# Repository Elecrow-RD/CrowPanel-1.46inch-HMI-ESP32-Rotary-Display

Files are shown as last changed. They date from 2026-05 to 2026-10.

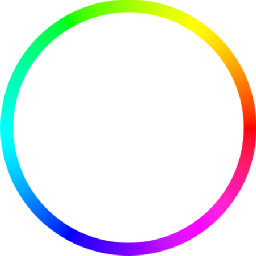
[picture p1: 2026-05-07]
factory_soucecode/1_46_SquareLine_Studio_Project/cache/thumb_327526221power_on_light_400@3x(1).png

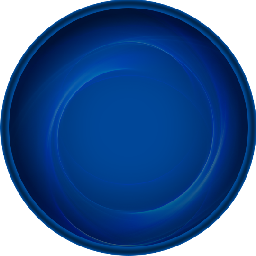
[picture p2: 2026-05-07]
factory_soucecode/1_46_SquareLine_Studio_Project/cache/thumb_1871530951device_control_bj_01@3x.png

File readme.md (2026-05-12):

### 1, Product picture



### 2, Product version number

| | Hardware | Software | Remark |
| ---- | --- | --- | --- |
| 1 | V1.0 | V1.0 | latest |

### 3, product information

#### Display Module Specifications
| Main Chip: ESP32-S3R8  | |
| --- | --- |
| Processor | Equipped with high-performance Xtensa 32-bit LX7 dual-core processor, with a main frequency of up to 240MHz |
| System memory | 512KB SRAM、8M PSRAM |
| Storage | 16M Flash |
| Screen | |
| Size | 1.46 inch |
| Screen Type | IPS |
| Touch Type | Capacitive Touch |
| Resolution | 360*360 |
| Wireless Communication | |
| Bluetooth | Bluetooth Low Energy and Bluetooth 5.0 |
| WiFi | Support 802.11a/b/g/n，2.4GH |
| Hardware | |
| UART Interface | 2x UART, ZX-MX 1.25-4P |
| I2C interface | ZX-MX 1.25-4P |
| FPC connector | 12P, Power supply burning port, Pitch: 0.5 mm. |
| Button | RESET button, BOOT button, confirmation button (knob press switch) |
| LED Light | Power indicator, LED ambient light |
| Other | |
| Power Input | 5V/1A |
| Operating temperature  | -20~65℃ |
| Storage temperature | -40~80℃ |
| Operation Power | Module：DC5V  Main Chip：3.3V |
| Size | 60\*60*27.5mm |
| Shell | Plastic + acrylic |
| Net Weight | 60g |

### 4, Use the driver module

| Name | dependency library |
| ---- | --- |
| LVGL | lvgl/lvgl@8.3.11 |

### 5,Quick Start

##### Arduino IDE starts

1.Download the library files used by this product to the 'libraries' folder.

C:\Users\Documents\Arduino\libraries\



2.Open the Arduino IDE



3.Open the code configuration environment and burn it.



### 6,Folder structure.

|--3D file： Contains 3D model files (.stp) for the hardware. These files can be used for visualization, enclosure design, or integration into CAD software.

|--Datasheet: Includes datasheets for components used in the project, providing detailed specifications, electrical characteristics, and pin configurations.

|--Eagle_SCH&PCB: Contains **Eagle CAD** schematic (`.sch`) and PCB layout (`.brd`) files. These are used for circuit design and PCB manufacturing.

|--example: Provides example code and projects to demonstrate how to use the hardware and libraries. These examples help users get started quickly.

|--factory_firmware: Stores pre-compiled factory firmware that can be directly flashed onto the device. This ensures the device runs the default functionality.

|--factory_sourcecode: Contains the source code for the factory firmware, allowing users to modify and rebuild the firmware as needed.

### 7,Pin definition

| Function | GPIO |
| --- | --- |
| LCD SCLK | GPIO10 |
| LCD MOSI | GPIO11 |
| LCD CS | GPIO9  |
| LCD DC | GPIO3  |
| LCD RST | GPIO14 |
| Touch SDA | GPIO6  |
| Touch SCL | GPIO7  |
| Touch INT | GPIO5  |
| Touch RST | GPIO13 |
| Backlight | GPIO46 |
| Encoder A | GPIO45 |
| Encoder B | GPIO42 |
| Encoder Switch | GPIO41 |
| Power LED | GPIO40 |
| RGB LED | GPIO48 |
| I2C_SDA | GPIO38 |
| I2C_SCL | GPIO39 |

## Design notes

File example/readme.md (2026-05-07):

**Arduino**: This folder contains sample programs for the Arduino platform, which is known for its ease of use and versatility in creating interactive electronic projects.

#### NOTE!!!:

#### 1.When running this program , you need to download the officially provided libraries and place them in the libraries of arduino. 

#### 2.esp32 version needs to be 2.0.14 the version of the libraries is the same as the officially provided version.

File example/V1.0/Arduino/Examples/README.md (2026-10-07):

# ESP32-S3 1.46 examples

These six sketches are hardware-adapted versions of `1.28Examples`. They target the 360x360 ST77961 display on the 1.46 board: LCD SPI 10/11/3/9/14, touch I2C SDA/SCL 6/7 with CST816T reset/interrupt 13/5, backlight GPIO46, power rails GPIO1/2, and indicator GPIO40. Encoder pins remain 45/42/button 41; DHT20 uses `Wire1` on 38/39. Each lesson that needs the shared display hardware includes its own Common_1_46.h, so every folder can be opened independently. Make the bundled `Arduino/RotaryScreen_1_46_Code_Core3_LVGL9/libraries` available as the sketchbook library directory.

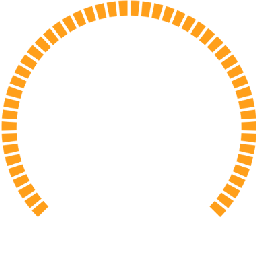
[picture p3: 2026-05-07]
factory_soucecode/1_46_SquareLine_Studio_Project/cache/thumb_1965436346bar_orange@3x.png

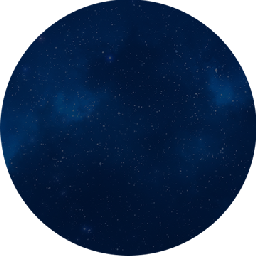
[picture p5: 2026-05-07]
factory_soucecode/1_46_SquareLine_Studio_Project/cache/thumb_440600382360_1.png

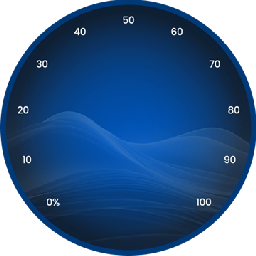
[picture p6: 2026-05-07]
factory_soucecode/1_46_SquareLine_Studio_Project/cache/thumb_309294278360_bg.png

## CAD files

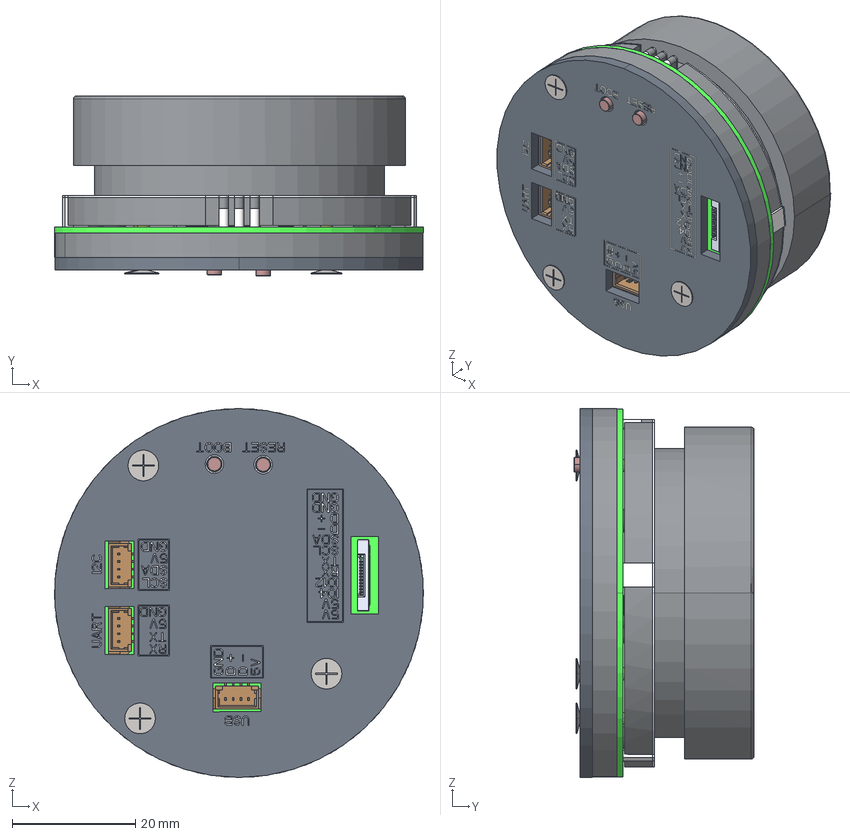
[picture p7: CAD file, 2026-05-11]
3D file/1.46_Rotary_Display_asm_1_asm.stp
60.0 x 29.3 x 60.0 mm
DIGAI-001_1
LED-SMD_WS2812B-4020_LED-SMD_WS x 8
SW-SMD_HX-4_5X4_5X5_0H-B3JTP__1 x 2
SW-SMD_HX-4_5X4_5X5_0H-B3JTP__2 x 2
FPC-SMD_12P-P0_50_X05C2012TZ__1
FPC-SMD_12P-P0_50_X05C2012TZ__2
FPC-SMD_12P-P0_50_X05C2012TZ__3
FPC-SMD_12P-P0_50_X05C2012TZ__4
FPC-SMD_12P-P0_50_X05C2012TZ__5
FPC-SMD_12P-P0_50_X05C2012TZ__6
FPC-SMD_12P-P0_50_X05C2012TZ__7
FPC-SMD_12P-P0_50_X05C2012TZ__8
FPC-SMD_12P-P0_50_X05C2012TZ__9
FPC-SMD_12P-P0_50_X05C2012TZ_10
FPC-SMD_12P-P0_50_X05C2012TZ_11
FPC-SMD_12P-P0_50_X05C2012TZ_13
FPC-SMD_12P-P0_50_X05C2012TZ_14
FPC-SMD_12P-P0_50_X05C2012TZ_12
CONN-SMD_4P-P1_25_MEGASTAR_ZX_1 x 2
CONN-SMD_4P-P1_25_MEGASTAR_ZX_2 x 2
CONN-SMD_4P-P1_25_MEGASTAR_ZX_3 x 2
P146B001-IPS_1
PRT0008_1_1
PRT0008_1_2
PRT0008_1_3
PRT0008_1_4
PRT0012_1
PRT0013_1
FPC-SMD_14P-P0_50_HC-FPC-05-2_1
FPC-SMD_14P-P0_50_HC-FPC-05-2_2
FPC-SMD_14P-P0_50_HC-FPC-05-2_3
FPC-SMD_14P-P0_50_HC-FPC-05-2_4
FPC-SMD_14P-P0_50_HC-FPC-05-2_5
FPC-SMD_14P-P0_50_HC-FPC-05-2_6
FPC-SMD_14P-P0_50_HC-FPC-05-2_7
FPC-SMD_14P-P0_50_HC-FPC-05-2_8
FPC-SMD_14P-P0_50_HC-FPC-05-2_9
FPC-SMD_14P-P0_50_HC-FPC-05-_10
FPC-SMD_14P-P0_50_HC-FPC-05-_11
FPC-SMD_14P-P0_50_HC-FPC-05-_12
FPC-SMD_14P-P0_50_HC-FPC-05-_13
FPC-SMD_14P-P0_50_HC-FPC-05-_14
FPC-SMD_14P-P0_50_HC-FPC-05-_15
FPC-SMD_14P-P0_50_HC-FPC-05-_16
FPC-SMD_14P-P0_50_HC-FPC-05-_17
FPC-SMD_14P-P0_50_HC-FPC-05-_18
FPC-SMD_14P-P0_50_HC-FPC-05-_19
FPC-SMD_14P-P0_50_HC-FPC-05-_20
FPC-SMD_14P-P0_50_HC-FPC-05-_21
FPC-SMD_14P-P0_50_HC-FPC-05-_22
FPC-SMD_14P-P0_50_HC-FPC-05-_23
FPC-SMD_14P-P0_50_HC-FPC-05-_24
FPC-SMD_14P-P0_50_HC-FPC-05-_25
FPC-SMD_14P-P0_50_HC-FPC-05-_26
FPC-SMD_14P-P0_50_HC-FPC-05-_27
FPC-SMD_14P-P0_50_HC-FPC-05-_28
FPC-SMD_14P-P0_50_HC-FPC-05-_29
FPC-SMD_14P-P0_50_HC-FPC-05-_30
FPC-SMD_14P-P0_50_HC-FPC-05-_31
ABF24D66-D606-482B-91E4-7AD95_1 x 3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

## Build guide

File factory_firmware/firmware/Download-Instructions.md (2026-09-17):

# RotaryScreen 1.46 Firmware Download Guide

> Version date: 2026-09-16
> What's new in this release: improved touch swipe feel when selecting items in the main menu (touch response on the detail page improved as well)

## Firmware Configuration

- Chip: ESP32-S3 (requires 16 MB Flash + OPI PSRAM)
- Arduino ESP32 Core: 3.3.8-cn
- Flash: 16 MB, 80 MHz, DIO
- PSRAM: OPI PSRAM
- Partition scheme: elecrow_s3 (10 MB APP)
- Boot sequence: shows the Screen0 splash image, enters the main menu (Screen1) after about 1.5 seconds

## Interaction Notes for This Version

| Action | Location | Effect |
| --- | --- | --- |
| Swipe left/right (≥30 px) | Main menu | Switch between Volume / Temp / Light, one step per swipe |
| Rotate the knob | Main menu | Same as above, switches one step at a time |
| Short press the knob | Main menu | Enter the detail page of the currently selected item |
| Drag the ring | Detail page | Adjust volume / temperature / brightness |
| Double press the knob | Detail page | Return to the main menu |

Main menu swiping uses a **one step per touch** strategy: continuing to swipe without lifting your finger will not skip through multiple steps — you need to lift your finger and swipe again to advance another step. This is an intentional design choice to avoid accidentally scrolling past several options on a mis-touch.

## Recommended Method: Flash the Complete Firmware in One Go

File to use: `RotaryScreen_1_46_ESP32S3_16MB_merged.bin` (16 MB, contains bootloader + partition table + application)

1. Connect the board with a USB cable.
2. Check Device Manager for the newly added COM port, for example `COM6`.
3. If the device does not enter download mode automatically: hold BOOT, briefly press RESET, then release BOOT.
4. Open a terminal in this directory and run:

```bat
flash_firmware.bat COM6
```

Replace `COM6` with the actual port. The device resets automatically after flashing succeeds.

You can also run esptool directly:

```bat
esptool.exe --chip esp32s3 --port COM6 --baud 921600 --before default-reset --after hard-reset write-flash -z --flash-mode dio --flash-freq 80m --flash-size 16MB 0x0 RotaryScreen_1_46_ESP32S3_16MB_merged.bin
```

If the connection is unstable, change the baud rate from `921600` to `115200`.

## Espressif Flash Download Tool

1. Select `ESP32-S3` as the chip and `Develop` as the mode.
2. Add `RotaryScreen_1_46_ESP32S3_16MB_merged.bin`.
3. Set the download address to `0x0`.
4. Set SPI SPEED to `80MHz`, SPI MODE to `DIO`, and FLASH SIZE to `16MB`.
5. Select the correct COM port and click START.

## Separate Firmware Flash Addresses

If you need to download the files separately, the files and addresses are as follows:

| Address | File |
| --- | --- |
| `0x0000` | `bootloader.bin` |
| `0x8000` | `partitions.bin` |
| `0xE000` | `boot_app0.bin` |
| `0x10000` | `RotaryScreen_1_46_app.bin` |

Note: when updating only the application, flash just `RotaryScreen_1_46_app.bin` to `0x10000`; for a first-time flash or when the partition layout changes, use the complete merged firmware.

## SHA-256 Checksums

See `SHA256SUMS.txt` in the same directory for the full list.

```text
RotaryScreen_1_46_ESP32S3_16MB_merged.bin  a19d0791915d7bf4e098c4388c402b202f067aa18c66ec787de13995972835cd
RotaryScreen_1_46_app.bin                  7330dbcaa128e9011c08a478efa70d9e7593d83b7891748ba2d3a0be162009bc
bootloader.bin                             b68c1ed33c43a4290375213f24d608c125e31e22880d16d4a5dcba89e083716d
partitions.bin                             0b9c3ff6810d66db6f419056f0fe49b118d8cf251049677e9475fae3fd0fb5d3
boot_app0.bin                              f94c5d786a7a8fab06ac5d10e33bf37711a6697636dc037559ea19cc410a17f0
```

Verification command on Windows:

```bat
certutil -hashfile RotaryScreen_1_46_ESP32S3_16MB_merged.bin SHA256
```

## FAQ

- **Stuck at `Connecting...`**: manually enter download mode (hold BOOT → briefly press RESET → release BOOT) and try again.
- **COM port not found**: use a USB cable that supports data transfer, or install the appropriate USB-to-serial driver.
- **Fails mid-flash**: close the serial monitor and lower the baud rate to `115200`.
- **Black screen or reset loop after flashing**: make sure the target hardware is an ESP32-S3 variant with 16 MB Flash and OPI PSRAM; a mismatched Flash or PSRAM configuration will cause boot failure.
- **Touch swipe still not responsive**: make sure you flashed the firmware from this directory (2026-09-16 version); older firmware used a different swipe threshold and trigger strategy in the main menu.

## File List

| File | Description |
| --- | --- |
| `RotaryScreen_1_46_ESP32S3_16MB_merged.bin` | Complete merged firmware, recommended |
| `RotaryScreen_1_46_app.bin` | Application only, for incremental updates on boards that have already been flashed with the complete firmware |
| `bootloader.bin` | Second-stage bootloader, address `0x0000` |
| `partitions.bin` | Partition table, address `0x8000` |
| `boot_app0.bin` | OTA boot data, address `0xE000` |
| `flash_firmware.bat` | One-click flashing script |
| `SHA256SUMS.txt` | SHA-256 checksum list |

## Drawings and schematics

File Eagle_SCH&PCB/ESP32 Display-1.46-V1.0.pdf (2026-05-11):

# POWER

3225_40M

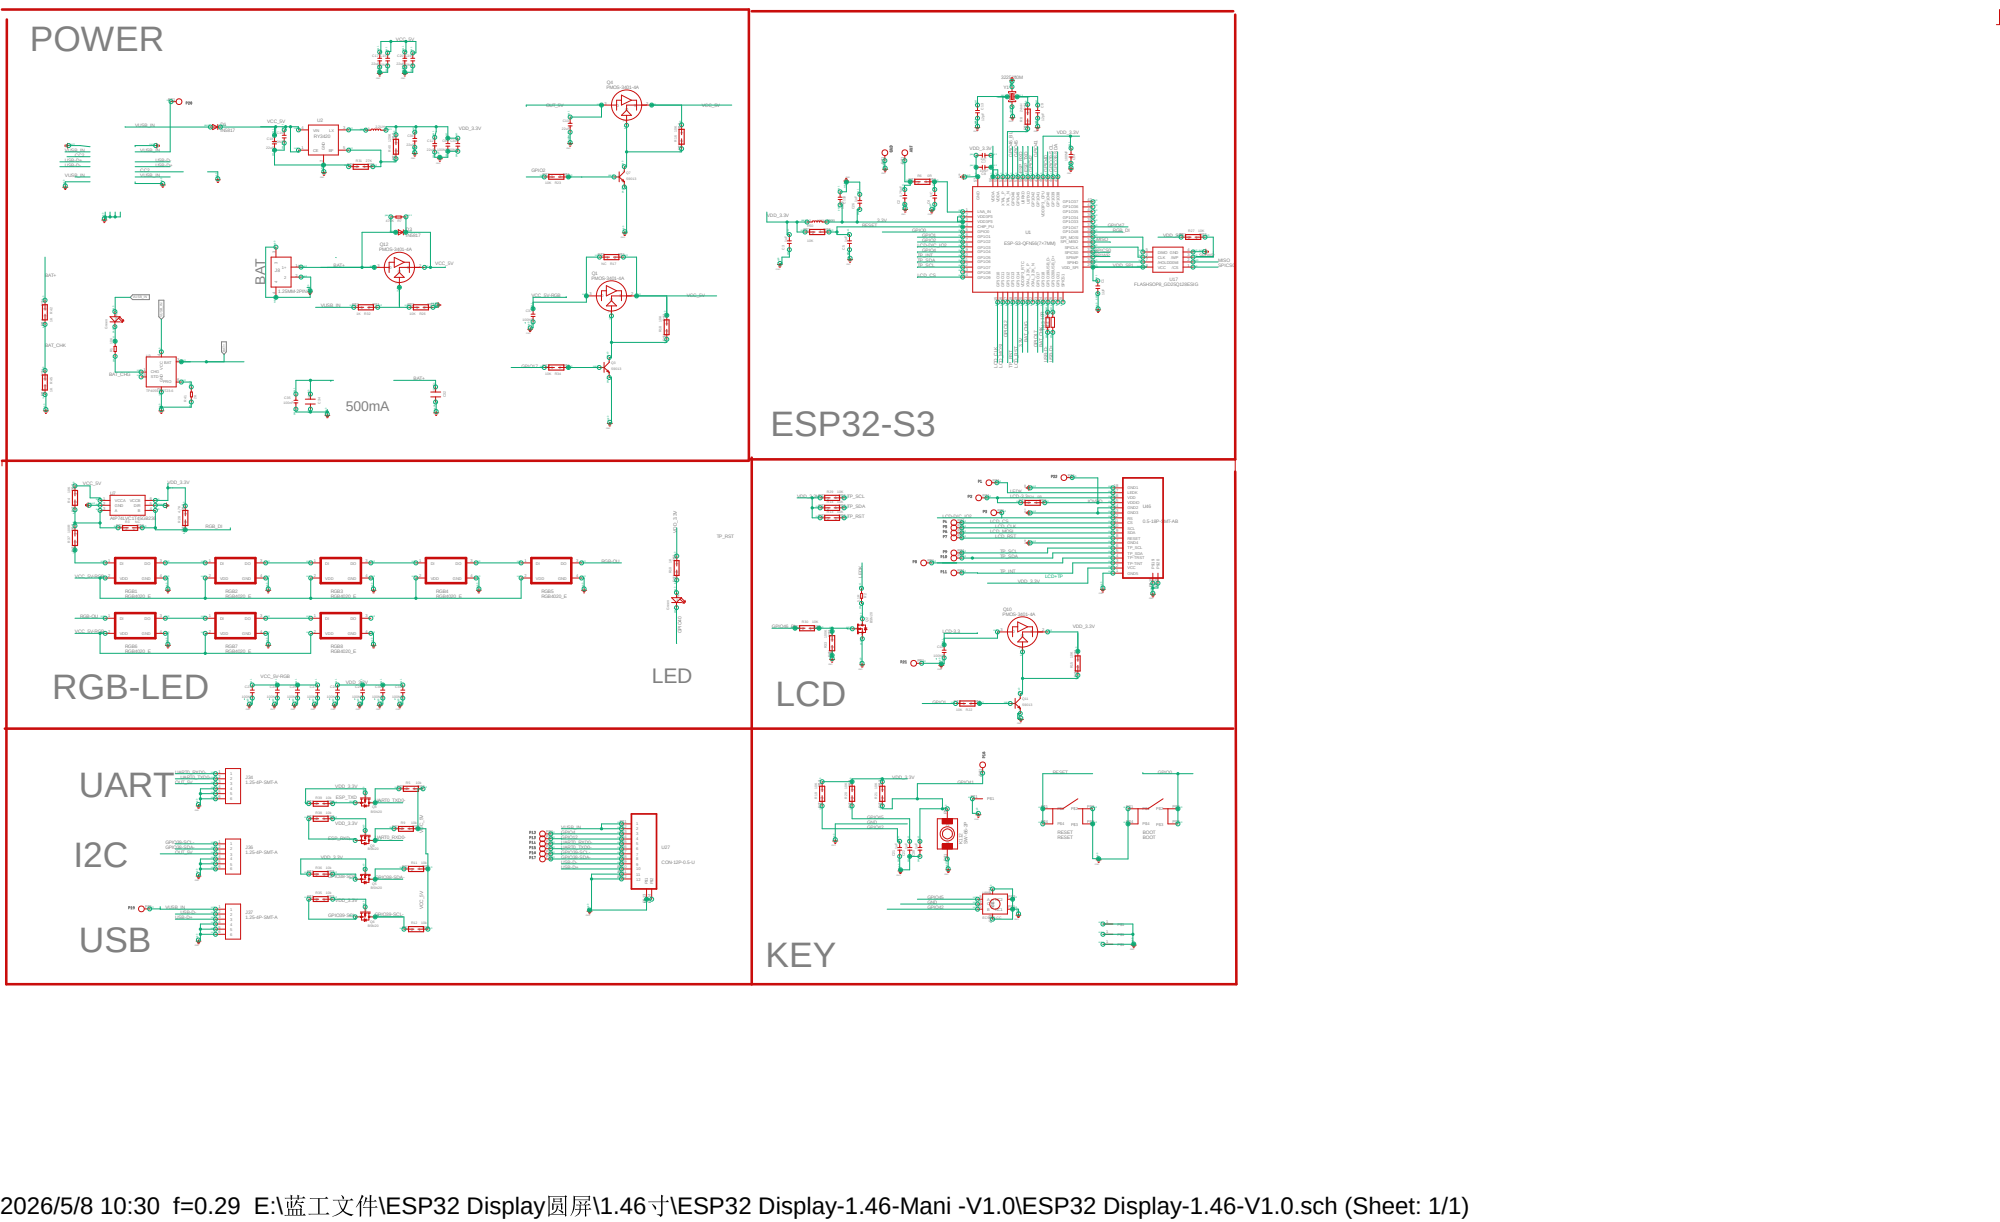
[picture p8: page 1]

pas 0 pas 0 sup 0 sup 0

io 0 io 0 io 0 io 0 sup 0

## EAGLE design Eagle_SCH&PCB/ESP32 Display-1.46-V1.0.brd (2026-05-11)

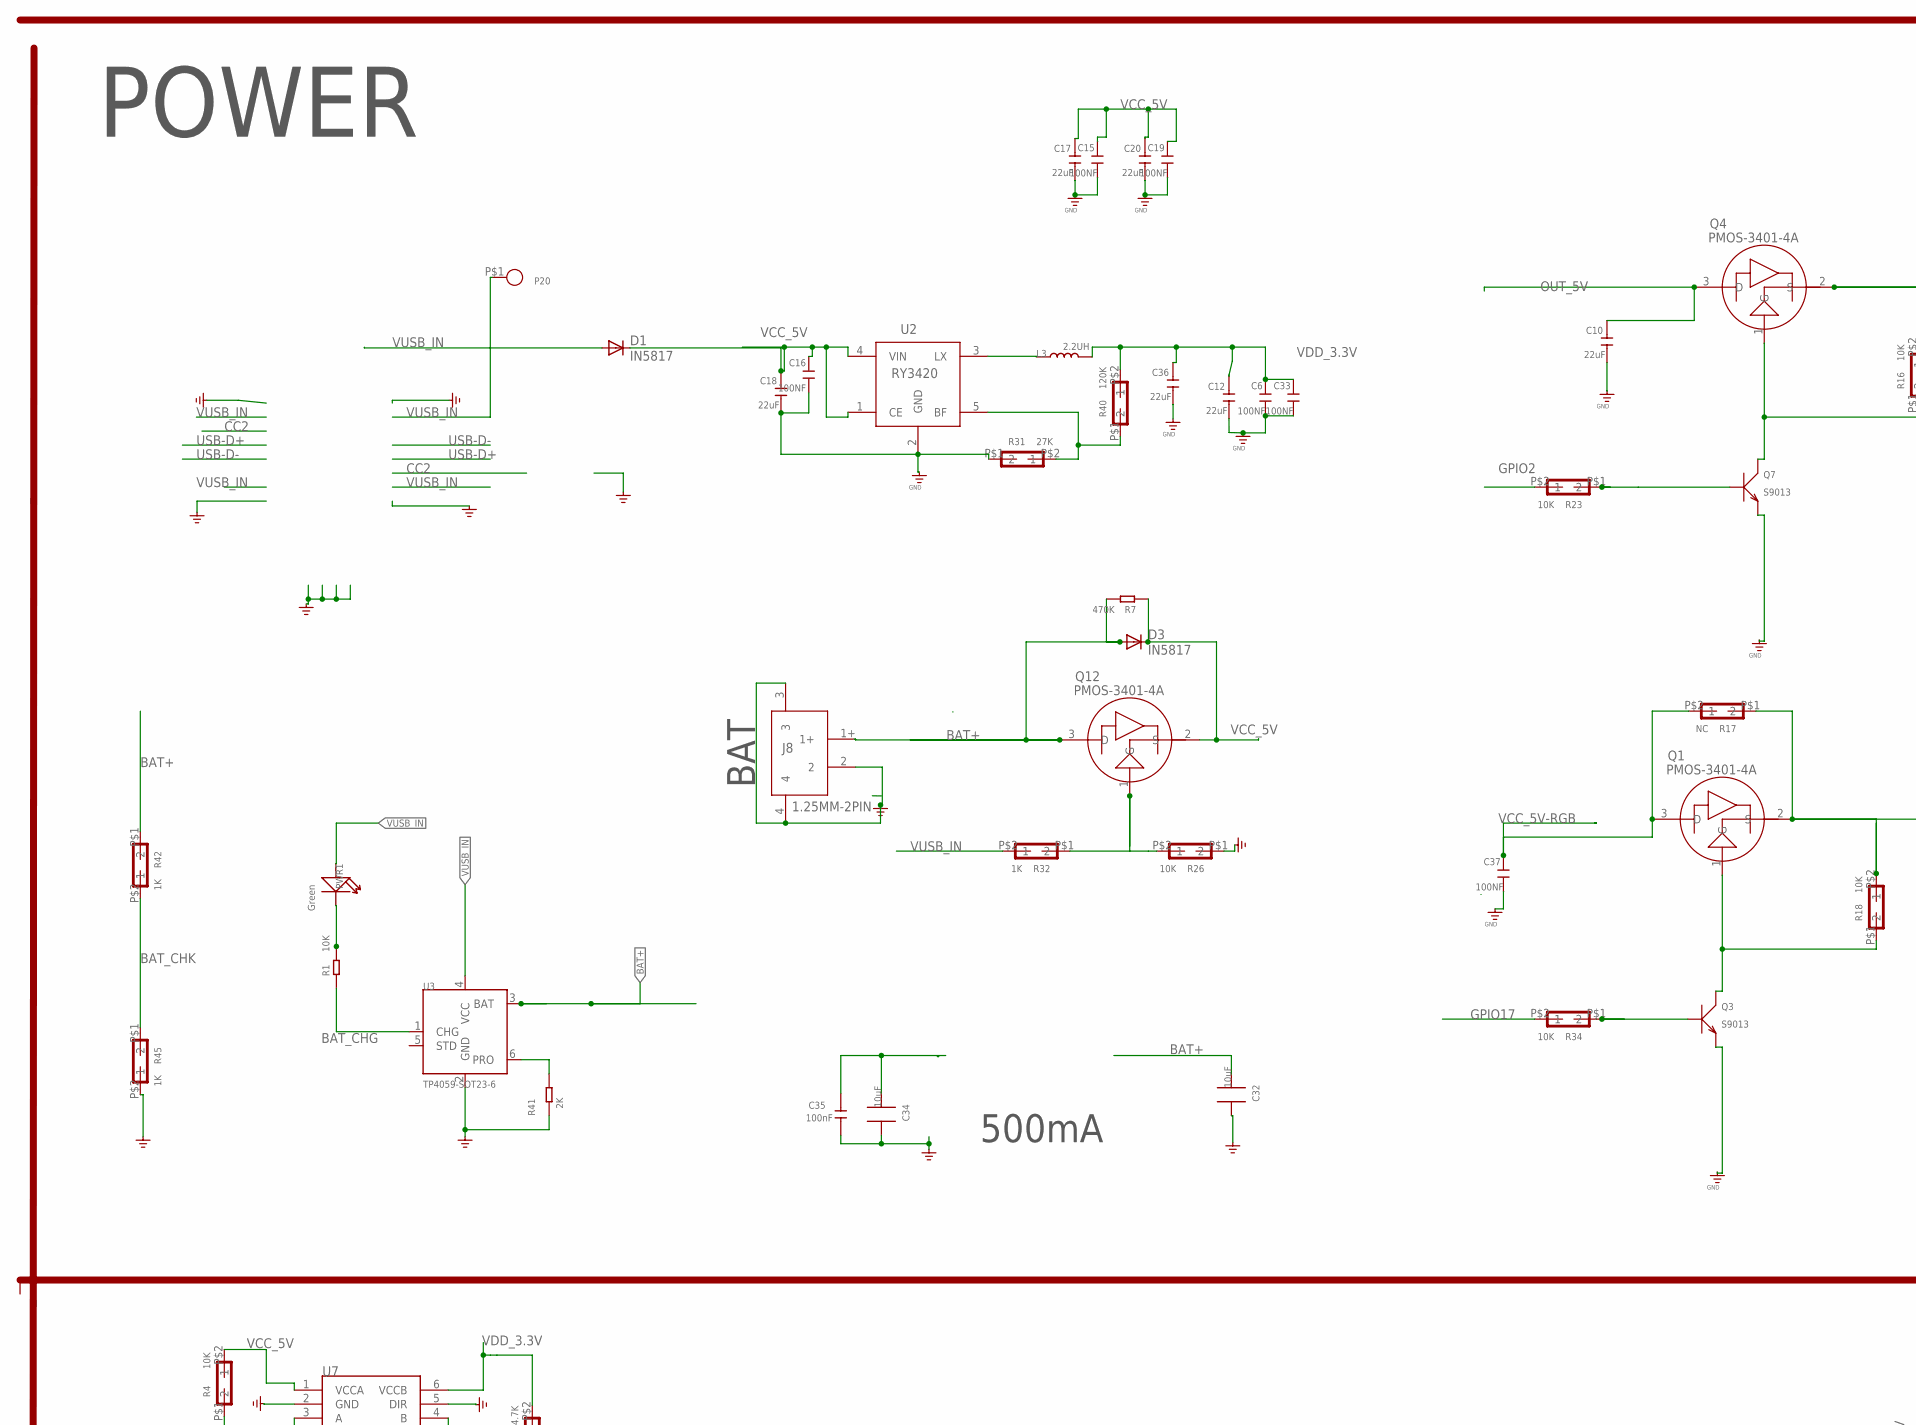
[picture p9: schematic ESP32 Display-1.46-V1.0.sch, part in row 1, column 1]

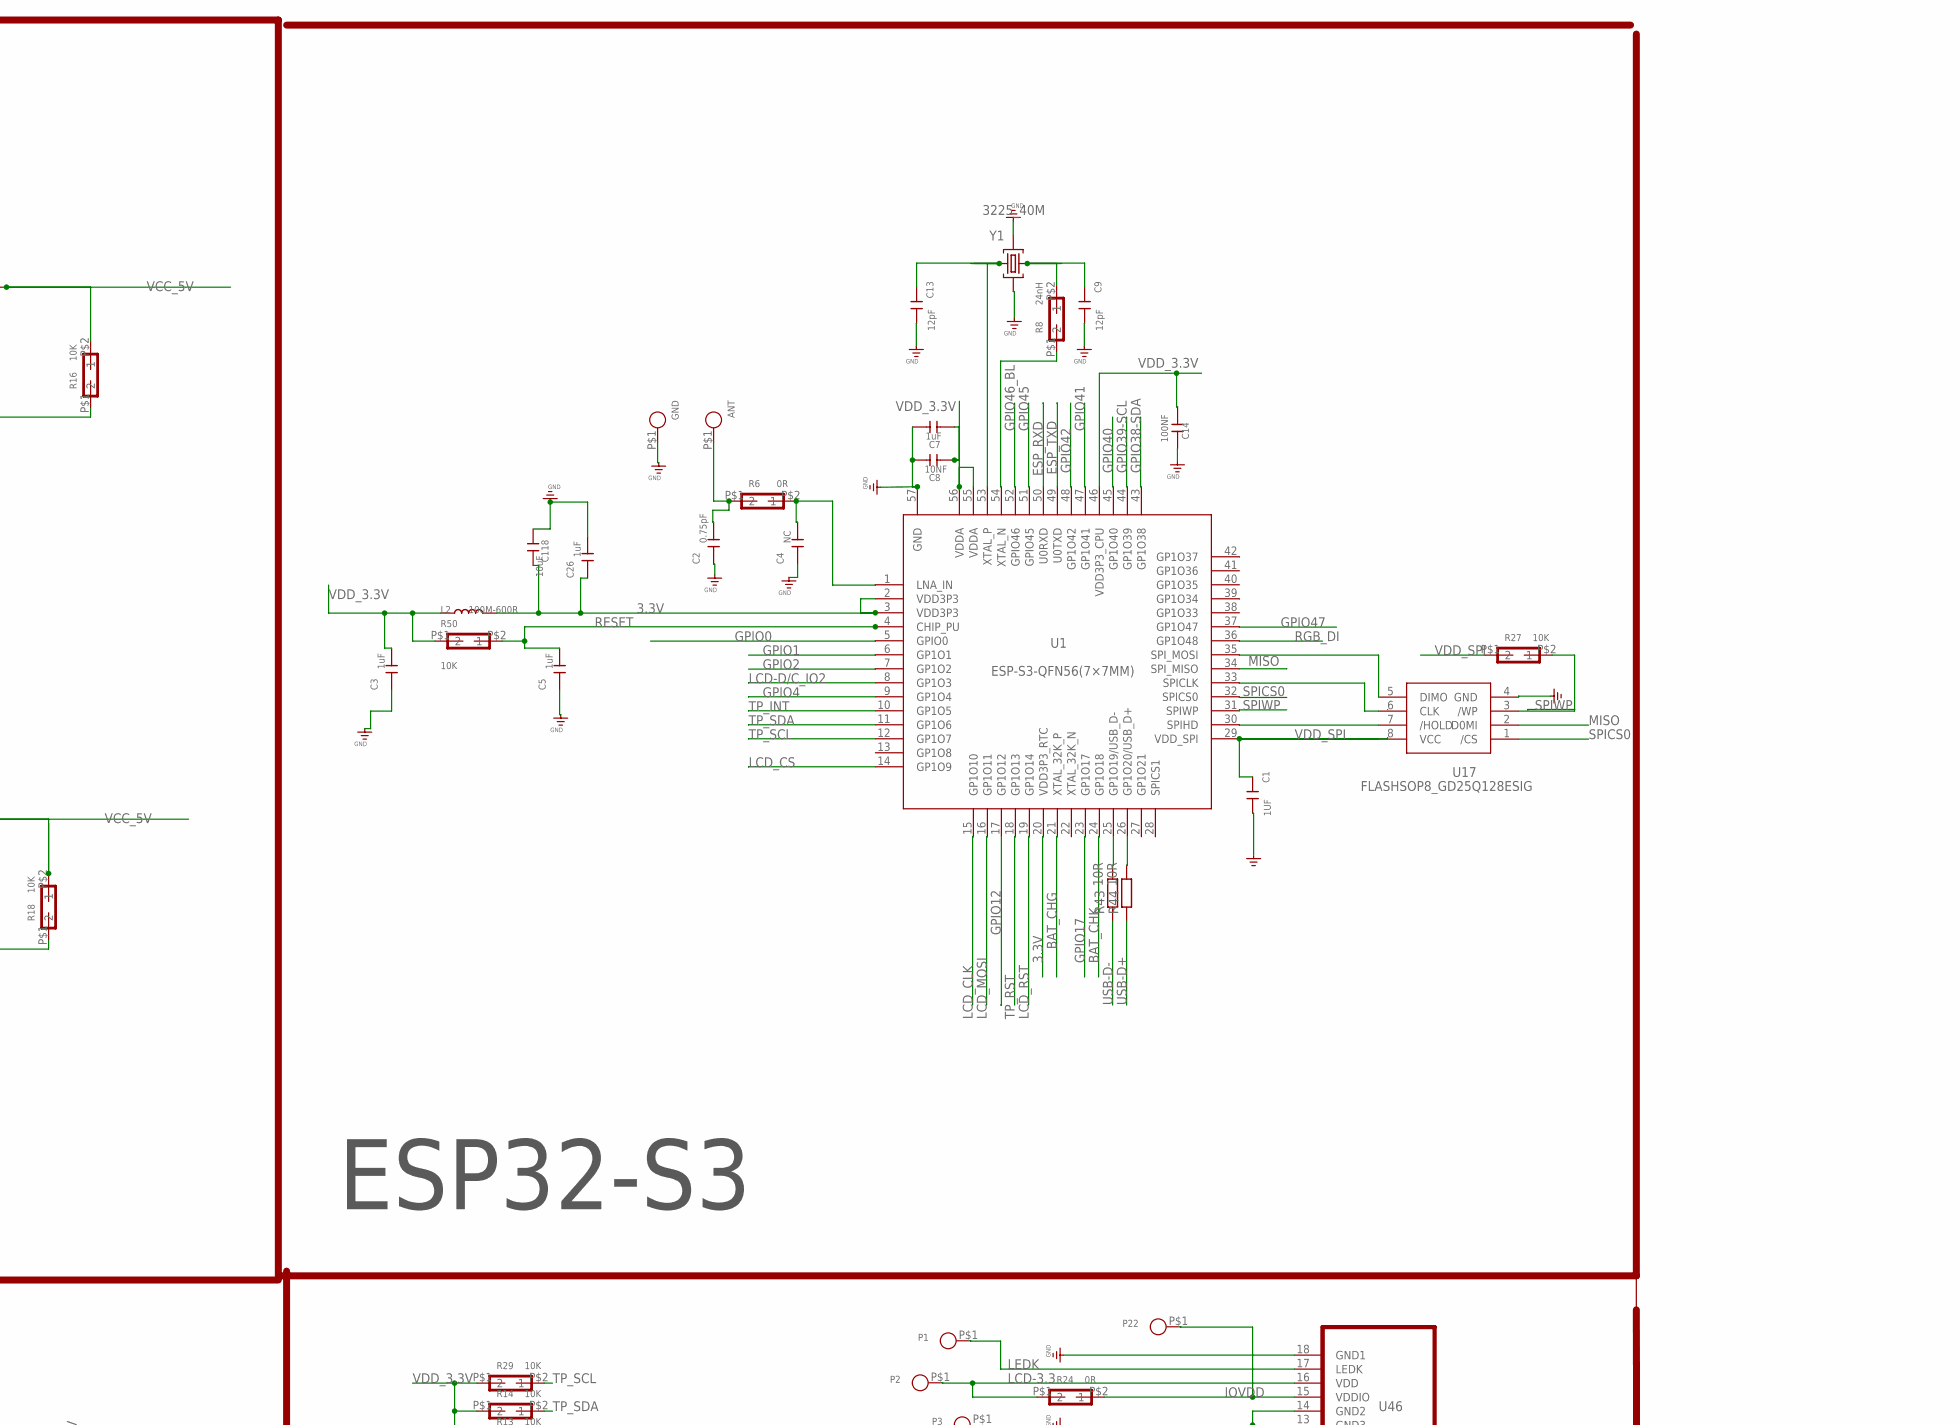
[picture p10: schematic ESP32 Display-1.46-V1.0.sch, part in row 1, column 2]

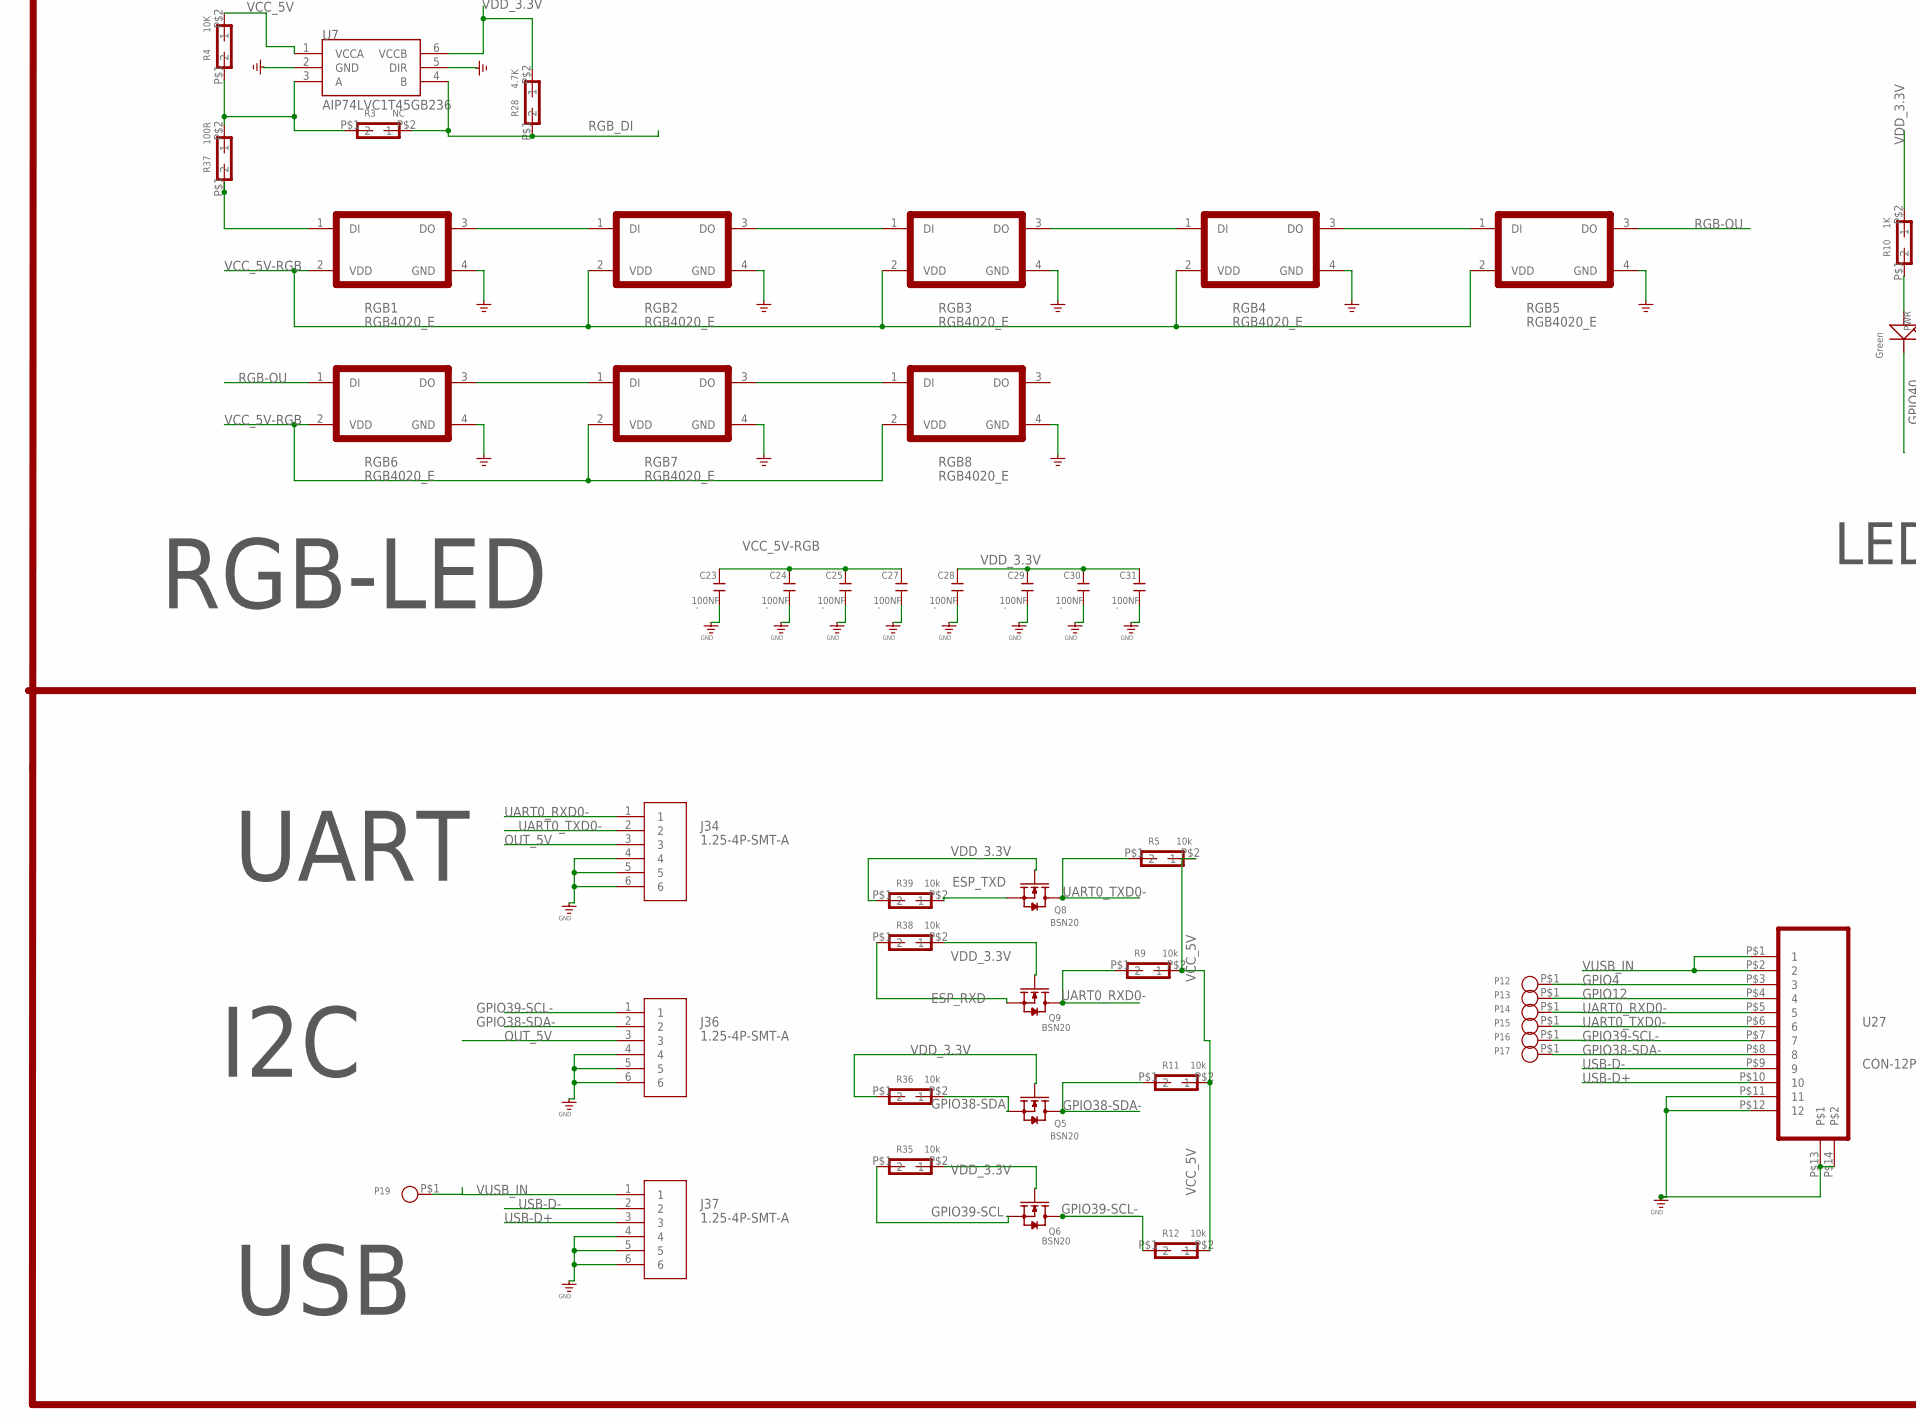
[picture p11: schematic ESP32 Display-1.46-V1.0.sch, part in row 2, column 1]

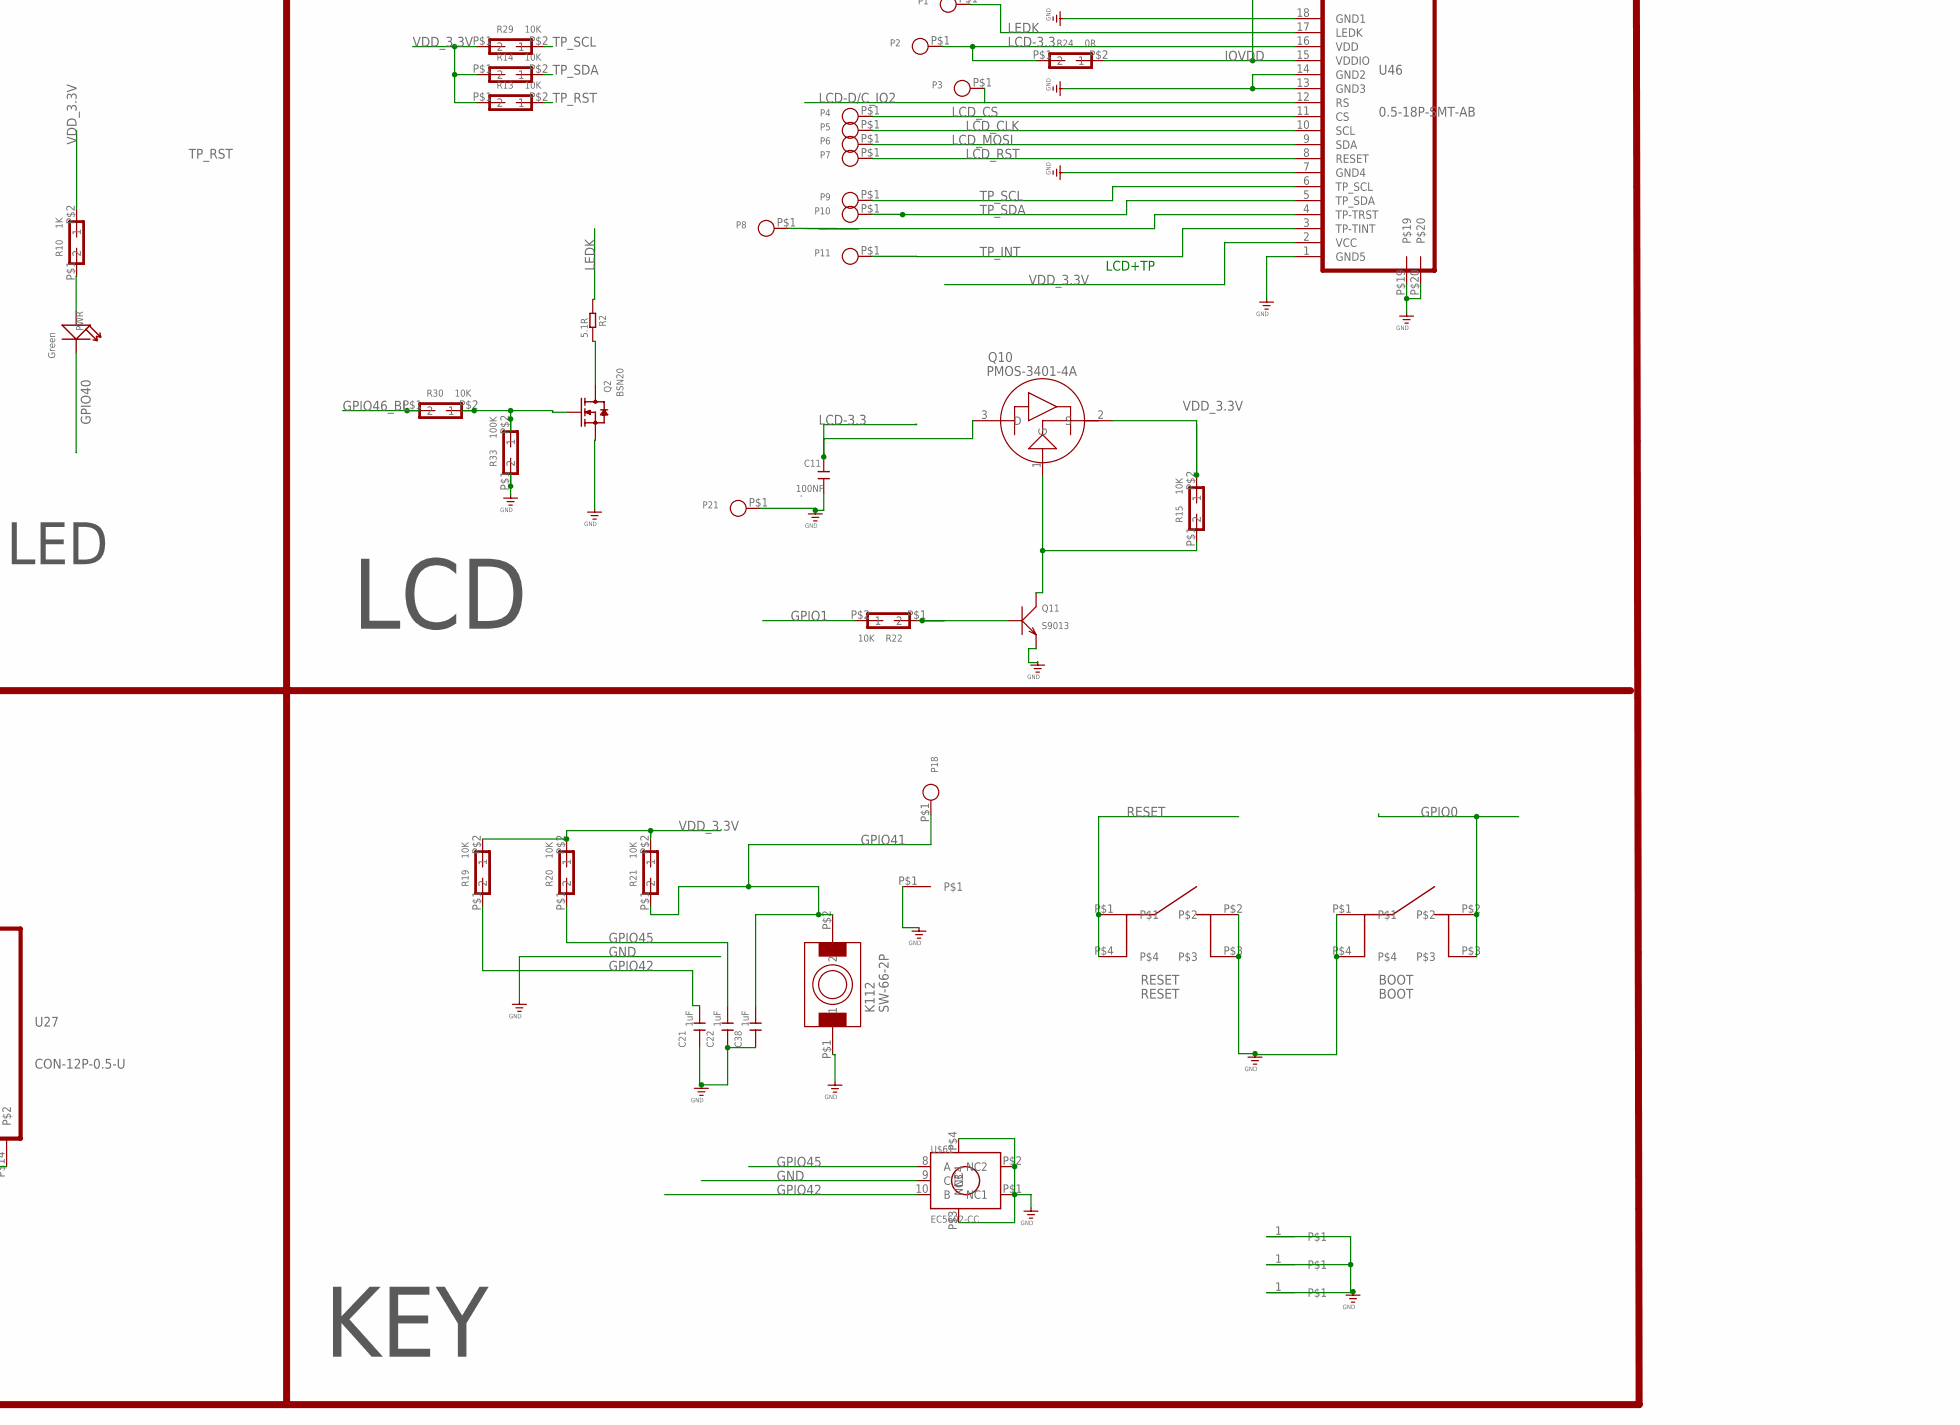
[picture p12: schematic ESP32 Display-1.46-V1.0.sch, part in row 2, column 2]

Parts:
ANT: TEST_PADPAD-1.5MM; TEST_PAD-1.5MM
BOOT: BOOT; SW-4.5*4.5
C1: 1UF; 0402
C2: 0.75pF; C0402
C3, C5, C21, C22, C26, C38: 1uF; C0402
C4: NC; C0402
C6, C11, C15, C16, C19, C23, C24, C25, C27, C28, C29, C30, C31, C33, C37: 100NF; 0603
C7: 1uF; C0603
C8: 10NF; C0603
C9, C13: 12pF; 0402
C10, C12, C17, C18, C20, C36: 22uF; 0805
C14: 100NF; C0603
C32, C34: 10uF; 0805_S
C35: 100nF; C0603
C118: 10uF; 0603
D1, D3: IN5817; DO-214AC
GND: TEST_PADPAD-1.5MM; TEST_PAD-1.5MM
J8: 1.25MM-2PIN; CROWBOT-V1.0库_1.25MM-2PIN
J34, J36, J37: 1.25-4P-SMT-A; 1.25-4P立贴
K112: SW-66-2P; CROWPI_POW_BUTTON_2P
L2: 100M-600R; L0603
L3: 2.2UH; L0420
P1, P2, P3, P4, P5, P6, P7, P8, P9, P10, P11, P12, P13, P14, P15, P16, P17, P18, P19, P20, P21, P22: PADPAD-1.0MM; PAD-1.0MM
PWR, PWR1: Green; LED-0603
Q1, Q4, Q10, Q12: PMOS-3401-4A; SOT-23
Q2, Q5, Q6, Q8, Q9: BSN20; SOT23
Q3, Q7, Q11: S9013; SOT23@1
R1: 10K; R0402
R2: 5.1R; R0603
R3, R17: NC; 0402
R4, R13, R14, R15, R16, R18, R19, R20, R21, R22, R23, R26, R27, R29, R30, R34, R50: 10K; 0402
R5, R9, R11, R12, R35, R36, R38, R39: 10k; 0402
R6, R24: 0R; 0402
R7: 470K; R0402
R8: 24nH; 0402
R10, R32, R42, R45: 1K; 0402
R28: 4.7K; 0402
R31: 27K; 0402
R33: 100K; 0402
R37: 100R; 0402
R40: 120K; 0402
R41: 2K; R0402
R43, R44: 10R; R0402
RESET: RESET; SW-4.5*4.5
RGB1, RGB2, RGB3, RGB4, RGB5, RGB6, RGB7, RGB8: RGB4020_E; RGB4020
T1, T2, T3: T2.5-A; T-2.5
U1: ESP-S3-QFN56(7×7MM)
U2: RY3420; SOT23-5
U3: TP4059-SOT23-6; SOT23-6L
U7: AIP74LVC1T45GB236; SOT23-6L
U17: FLASHSOP8_GD25Q128ESIG; FLASHSOP8_SOP8
U27: CON-12P-0.5-U; CON-0.5-12P-U
U46: 0.5-18P-SMT-AB; 0.5MM-18P
U$61: EC5602-CC
U$64: T-2-1.1
Y1: 3225_40M; CRYSTAL-3.2-2.5

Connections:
3.3V: C26.1, C118.2, L2.2, U1.2 (VDD3P3), U1.3 (VDD3P3), U1.20 (VDD3P3_RTC)
BAT+: C32.2, D3.A, J8.1+, Q12.3 (D), R7.1, R42.P$1 (1), U3.3 (BAT)
BAT_CHG: R1.2, U1.21 (XTAL_32K_P), U3.1 (CHG)
BAT_CHK: R42.P$2 (2), R45.P$1 (1), U1.24 (GP1O18)
ESP_RXD: Q9.2 (S), R38.P$1 (1), U1.50 (U0RXD)
ESP_TXD: Q8.2 (S), R39.P$2 (2), U1.49 (U0TXD)
GND: BOOT.P$1, BOOT.P$4, C1.2, C2.1, C3.1, C4.1, C5.1, C6.2, C7.2, C8.2, C9.2, C10.1, C11.2, C12.1, C13.2, C14.2, C15.2, C16.2, C17.1, C18.1, C19.2, C20.1, C21.1, C22.1, C23.2, C24.2, C25.2, C26.2, C27.2, C28.2, C29.2, C30.2, C31.2, C32.1, C33.2, C34.1, C35.2, C36.1, C37.2, C38.1, C118.1, GND.P$1, J8.2, J8.3, J8.4, J34.4, J34.5, J34.6, J36.4, J36.5, J36.6, J37.4, J37.5, J37.6, K112.P$1 (1), P21.P$1, Q2.2 (S), Q3.2 (E), Q7.2 (E), Q11.2 (E), R26.P$1 (1), R31.P$1 (1), R33.P$1 (1), R41.1, R45.P$2 (2), RESET.P$2, RESET.P$3, RGB1.4 (GND), RGB2.4 (GND), RGB3.4 (GND), RGB4.4 (GND), RGB5.4 (GND), RGB6.4 (GND), RGB7.4 (GND), RGB8.4 (GND), T1.1, T2.1, T3.1, U1.57 (GND), U2.2 (GND), U3.2 (GND), U7.2 (GND), U7.5 (DIR), U17.4 (GND), U27.P$11 (11), U27.P$12 (12), U27.P$13, U27.P$14, U46.1 (GND5), U46.7 (GND4), U46.13 (GND3), U46.14 (GND2), U46.18 (GND1), U46.P$19, U46.P$20, U$61.9 (C), U$61.P$1 (NC1), U$61.P$2 (NC2), U$61.P$3 (NC3), U$61.P$4 (NC4), U$64.P$1, Y1.2 (GND), Y1.4 (GND)
GPIO0: BOOT.P$2, BOOT.P$3, U1.5 (GPIO0)
GPIO1: R22.P$2 (2), U1.6 (GP1O1)
GPIO2: R23.P$2 (2), U1.7 (GP1O2)
GPIO4: P12.P$1, U1.9 (GP1O4), U27.P$3 (3)
GPIO12: P13.P$1, U1.17 (GP1O12), U27.P$4 (4)
GPIO17: R34.P$2 (2), U1.23 (GP1O17)
GPIO34: U1.39 (GP1O34)
GPIO37: U1.42 (GP1O37)
GPIO38-SDA: Q5.2 (S), R36.P$2 (2), U1.43 (GP1O38)
GPIO38-SDA-: J36.2, P17.P$1, Q5.3 (D), R11.P$1 (1), U27.P$8 (8)
GPIO39-SCL: Q6.2 (S), R35.P$1 (1), U1.44 (GP1O39)
GPIO39-SCL-: J36.1, P16.P$1, Q6.3 (D), R12.P$1 (1), U27.P$7 (7)
GPIO40: PWR.-, U1.45 (GP1O40)
GPIO41: C38.2, K112.P$2 (2), P18.P$1, R21.P$1 (1), U1.47 (GP1O41)
GPIO42: C21.2, R19.P$1 (1), U1.48 (GP1O42), U$61.10 (B)
GPIO45: C22.2, R20.P$1 (1), U1.51 (GPIO45), U$61.8 (A)
GPIO46_BL: R30.P$1 (1), U1.52 (GPIO46)
GPIO47: U1.37 (GP1O47)
IOVDD: P22.P$1, R24.P$2 (2), U46.15 (VDDIO)
LCD-3.3: C11.1, P2.P$1, Q10.3 (D), R24.P$1 (1), U46.16 (VDD)
LCD-D/C_IO2: P3.P$1, U1.8 (GP1O3), U46.12 (RS)
LCD_CLK: P5.P$1, U1.15 (GP1O10), U46.10 (SCL)
LCD_CS: P4.P$1, U1.14 (GP1O9), U46.11 (CS)
LCD_MOSI: P6.P$1, U1.16 (GP1O11), U46.9 (SDA)
LCD_RST: P7.P$1, U1.19 (GP1O14), U46.8 (RESET)
LEDK: P1.P$1, R2.2, U46.17 (LEDK)
MISO: U1.34 (SPI_MISO), U17.2 (D0MI)
unnamed: Q4.1 (G), Q7.3 (C), R16.P$1 (1)
unnamed: RGB1.3 (DO), RGB2.1 (DI)
unnamed: L3.1, U2.3 (LX)
unnamed: RGB2.3 (DO), RGB3.1 (DI)
unnamed: PWR.+, R10.P$1 (1)
unnamed: ANT.P$1, C2.2, R6.P$1 (1)
unnamed: RGB3.3 (DO), RGB4.1 (DI)
unnamed: R43.2, U1.25 (GP1O19/USB_D-)
unnamed: R41.2, U3.6 (PRO)
unnamed: Q12.1 (G), R26.P$2 (2), R32.P$1 (1)
unnamed: Q2.3 (D), R2.1
unnamed: R31.P$2 (2), R40.P$1 (1), U2.5 (BF)
unnamed: Q2.1 (G), R30.P$2 (2), R33.P$2 (2)
unnamed: R44.2, U1.26 (GP1O20/USB_D+)
unnamed: R3.P$1 (1), R4.P$1 (1), R37.P$2 (2), U7.3 (A)
unnamed: R37.P$1 (1), RGB1.1 (DI)
unnamed: U1.35 (SPI_MOSI), U17.5 (DIMO)
unnamed: U1.33 (SPICLK), U17.6 (CLK)
unnamed: RGB4.3 (DO), RGB5.1 (DI)
unnamed: U1.30 (SPIHD), U17.7 (/HOLD)
unnamed: Q10.1 (G), Q11.3 (C), R15.P$1 (1)
unnamed: Q11.1 (B), R22.P$1 (1)
unnamed: Q7.1 (B), R23.P$1 (1)
unnamed: RGB6.3 (DO), RGB7.1 (DI)
unnamed: RGB7.3 (DO), RGB8.1 (DI)
unnamed: Q1.1 (G), Q3.3 (C), R18.P$1 (1)
unnamed: Q3.1 (B), R34.P$1 (1)
unnamed: PWR1.-, R1.1
unnamed: C9.1, R8.P$2 (2), Y1.1 (C1)
unnamed: R8.P$1 (1), U1.54 (XTAL_N)
unnamed: C4.2, R6.P$2 (2), U1.1 (LNA_IN)
unnamed: C13.1, U1.53 (XTAL_P), Y1.3 (C2)
OUT_5V: C10.2, J34.3, J36.3, Q4.3 (D)
RESET: C5.2, R50.P$2 (2), RESET.P$1, RESET.P$4, U1.4 (CHIP_PU)
RGB-OU: RGB5.3 (DO), RGB6.1 (DI)
RGB_DI: R3.P$2 (2), R28.P$1 (1), U1.36 (GP1O48), U7.4 (B)
SPICS0: U1.32 (SPICS0), U17.1 (/CS)
SPIWP: R27.P$2 (2), U1.31 (SPIWP), U17.3 (/WP)
TP_INT: P11.P$1, U1.10 (GP1O5), U46.3 (TP-TINT)
TP_RST: P8.P$1, R13.P$2 (2), U1.18 (GP1O13), U46.4 (TP-TRST)
TP_SCL: P9.P$1, R29.P$2 (2), U1.12 (GP1O7), U46.6 (TP_SCL)
TP_SDA: P10.P$1, R14.P$2 (2), U1.11 (GP1O6), U46.5 (TP_SDA)
UART0_RXD0-: J34.1, P14.P$1, Q9.3 (D), R9.P$1 (1), U27.P$5 (5)
UART0_TXD0-: J34.2, P15.P$1, Q8.3 (D), R5.P$1 (1), U27.P$6 (6)
USB-D+: J37.3, R44.1, U27.P$10 (10)
USB-D-: J37.2, R43.1, U27.P$9 (9)
VCC_5V: C15.1, C16.1, C17.2, C18.2, C19.1, C20.2, D1.C, D3.C, Q1.2 (S), Q4.2 (S), Q12.2 (S), R4.P$2 (2), R5.P$2 (2), R7.2, R9.P$2 (2), R11.P$2 (2), R12.P$2 (2), R16.P$2 (2), R17.P$1 (1), R18.P$2 (2), U2.1 (CE), U2.4 (VIN), U7.1 (VCCA)
VCC_5V-RGB: C23.1, C24.1, C25.1, C27.1, C37.1, Q1.3 (D), R17.P$2 (2), RGB1.2 (VDD), RGB2.2 (VDD), RGB3.2 (VDD), RGB4.2 (VDD), RGB5.2 (VDD), RGB6.2 (VDD), RGB7.2 (VDD), RGB8.2 (VDD)
VDD_3.3V: C3.2, C6.1, C7.1, C8.1, C12.2, C14.1, C28.1, C29.1, C30.1, C31.1, C33.1, C36.2, L2.1, L3.2, Q5.1 (G), Q6.1 (G), Q8.1 (G), Q9.1 (G), Q10.2 (S), R10.P$2 (2), R13.P$1 (1), R14.P$1 (1), R15.P$2 (2), R19.P$2 (2), R20.P$2 (2), R21.P$2 (2), R28.P$2 (2), R29.P$1 (1), R35.P$2 (2), R36.P$1 (1), R38.P$2 (2), R39.P$1 (1), R40.P$2 (2), R50.P$1 (1), U1.46 (VDD3P3_CPU), U1.55 (VDDA), U1.56 (VDDA), U7.6 (VCCB), U46.2 (VCC)
VDD_SPI: C1.1, R27.P$1 (1), U1.29 (VDD_SPI), U17.8 (VCC)
VUSB_IN: C34.2, C35.1, D1.A, J37.1, P19.P$1, P20.P$1, PWR1.+, R32.P$2 (2), U3.4 (VCC), U27.P$1 (1), U27.P$2 (2)

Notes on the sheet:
LED
RGB-LED
ESP32-S3
LCD+TP
UART
I2C
USB
LCD
POWER
KEY
BAT
500mA

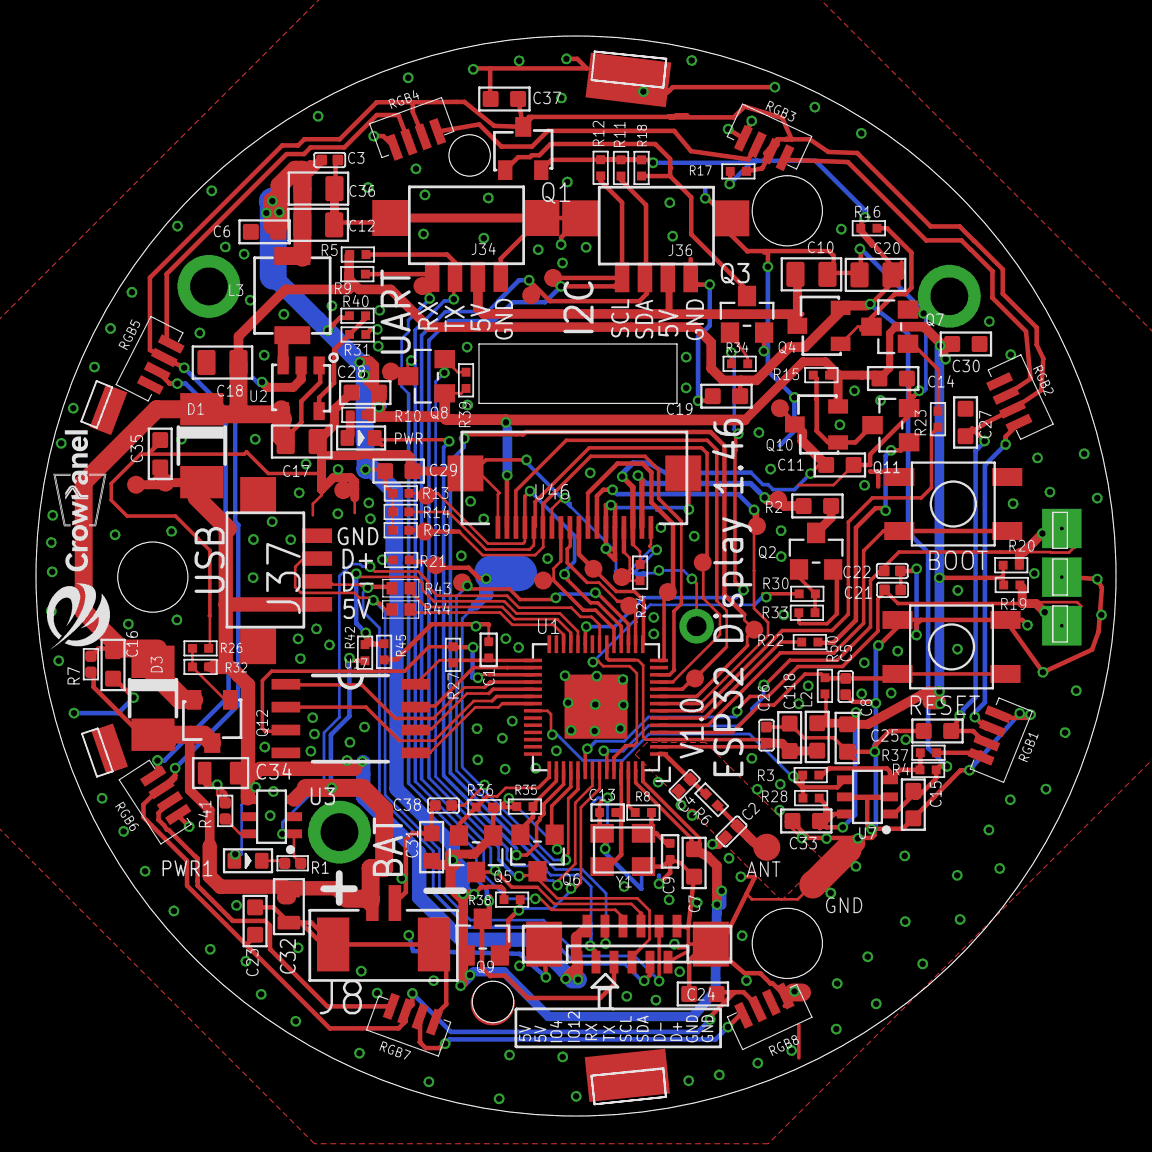
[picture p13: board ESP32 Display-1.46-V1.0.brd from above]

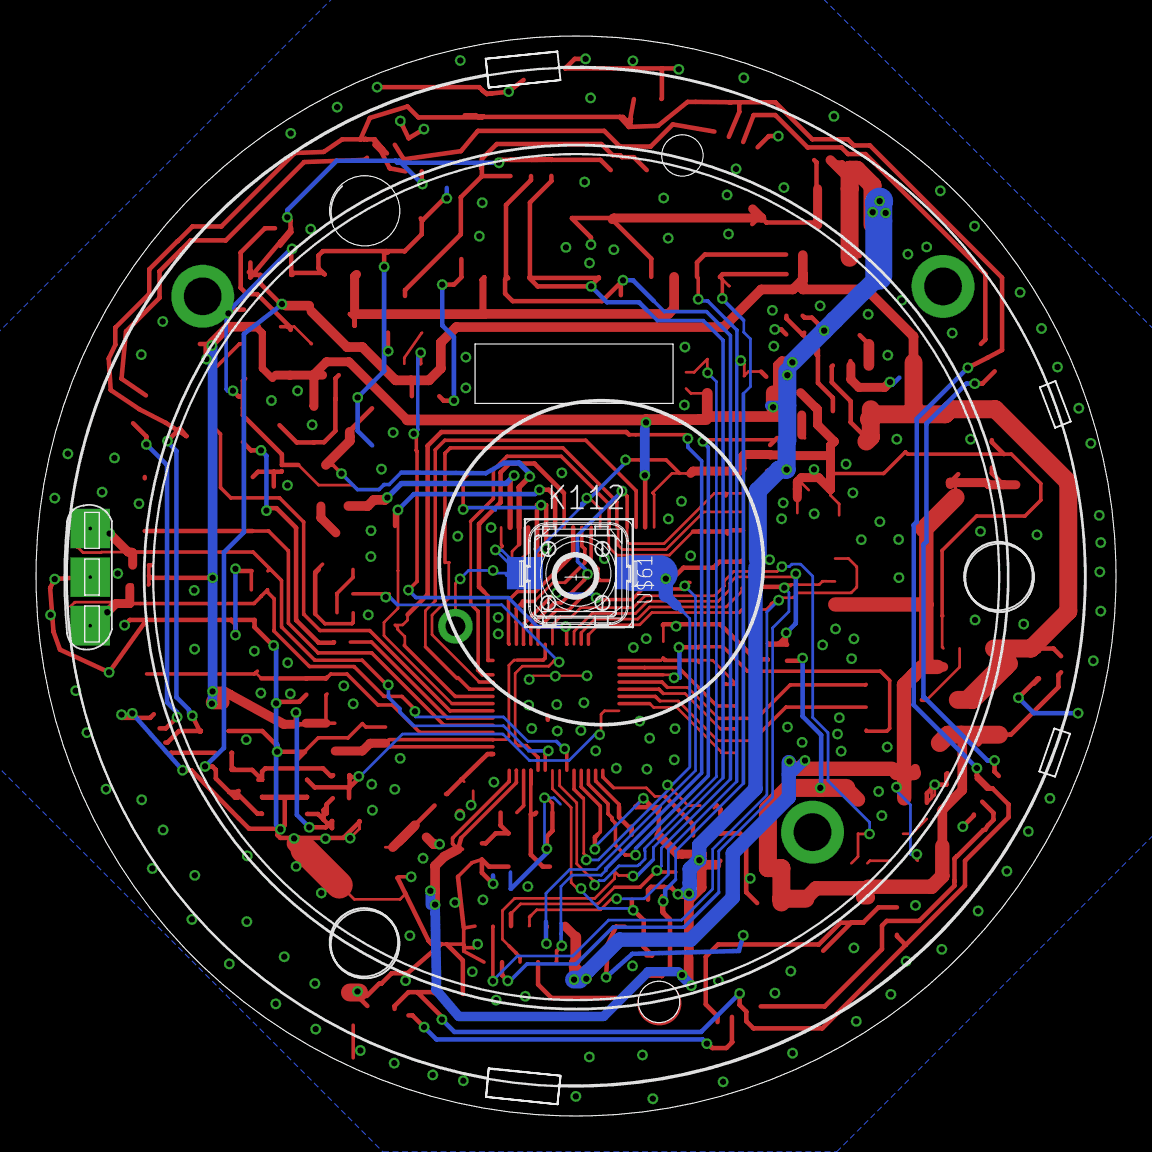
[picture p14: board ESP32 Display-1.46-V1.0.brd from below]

Board: 2 copper layers, 60.0 x 60.0 mm, 156 parts (2 on the bottom side), 82 nets.

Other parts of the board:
U$9: LOGO-1.46
U$51: LOGO公司图标

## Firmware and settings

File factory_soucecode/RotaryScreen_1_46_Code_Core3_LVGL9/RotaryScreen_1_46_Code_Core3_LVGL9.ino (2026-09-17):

/*---------------------------------------------------------------
 * Project configuration
 * Load the board definition and all display, touch, and UI objects.
 *--------------------------------------------------------------*/
// Reserved LovyanGFX option retained from the original project.
// #define LGFX_AUTOBUFFERmy_disp_flush
#include "RotaryScreen_1_46.h"
/*
 * LVGL 9.1 exposes the indev tuning fields (scroll_limit, gesture_limit,
 * scroll_throw) only through the private header.  Including it lets the
 * small 360x360 knob display get the lower drag/gesture thresholds it
 * needs without modifying any library source files.
 */
#include "indev/lv_indev_private.h"

/*---------------------------------------------------------------
 * I2C and touch devices
 * Use the default Wire bus for touch and a second bus for board use.
 *--------------------------------------------------------------*/
// Auxiliary controller created on ESP32 I2C port 1.
TwoWire IIC = TwoWire(1); 
// Indirection retained so the touch bus pins can be assigned in setup().
static TwoWire* wi = &Wire;

// CST816T touch controller using Wire, interrupt GPIO 13, and reset GPIO 5.
cst816t touch = cst816t(Wire, 13, 5);
 
/*---------------------------------------------------------------
 * RTOS task handles
 * Keep references to the independent LED and encoder worker tasks.
 *--------------------------------------------------------------*/
TaskHandle_t ledTestTaskHandle = NULL;
TaskHandle_t encTaskHandle = NULL;

enum EncoderActionType : int8_t {
  ENCODER_ROTATE_UP = 1,
  ENCODER_ROTATE_DOWN,
  ENCODER_SINGLE_CLICK,
  ENCODER_DOUBLE_CLICK
};

struct EncoderAction {
  EncoderActionType type;
};

QueueHandle_t encoderActionQueue = NULL;

void processEncoder();
void updataScreen(int index);
extern lv_obj_t *current_screen;

// Selected main-menu item: 0 for Volume, 1 for Temp, and 2 for Light.
int screen1_index = 1;

/**
 * @brief Select a neighboring Screen1 item with a horizontal swipe.
 *
 * Kept as a stub for source compatibility.  The active menu-switch logic
 * now lives inside my_touchpad_read(), which mirrors the manual swipe
 * detection used by the 1.28-inch reference firmware (30 px threshold,
 * horizontal-dominant, one switch per touch).
 */
static void screen1_gesture_event_cb(lv_event_t *e) {
  (void)e;
}

/**
 * @brief Finish the startup screen and open the interactive main menu.
 */
static void startup_screen_timeout_cb(lv_timer_t *timer) {
  (void)timer;
  if (ui_Screen1 != NULL) {
    lv_screen_load_anim(ui_Screen1, LV_SCR_LOAD_ANIM_FADE_ON, 250, 0, false);
    current_screen = ui_Screen1;
  }
}

/*---------------------------------------------------------------
 * LVGL display state
 * Hold two PSRAM frame buffers and the registered display object.
 *--------------------------------------------------------------*/
static uint8_t *buf = NULL;
static uint8_t *buf1 = NULL;
static lv_display_t *display = NULL;

// Screen pointer queried before routing encoder and button actions.
lv_obj_t *current_screen = NULL;

// Enable this macro only when touch-coordinate logging is required.
//#define DEBUG_PRINT

/*---------------------------------------------------------------
 * Encoder push-button interrupt
 * Capture short button events without performing UI work in the ISR.
 *--------------------------------------------------------------*/
/**
 * @brief Record an accepted encoder push-button edge.
 *
 * Applies a time-based debounce check, updates the shared press state,
 * and counts clicks for later single- or double-click classification.
 * UI transitions are deferred to encTask() because they are not safe
 * operations for an interrupt service routine.
 *
 * @note Parameters: None; the function is installed as a GPIO ISR.
 * @return Nothing.
 * @note Called on each falling edge detected on SWITCH_PIN.
 */
void IRAM_ATTR buttonISR() {
  static unsigned long lastInterruptTime = 0;
  unsigned long interruptTime = millis();

  // Ignore mechanical bounce until the active debounce interval expires.
  if (interruptTime - lastInterruptTime > debounceTime) {
    debounceTime = 40;
    if (digitalRead(SWITCH_PIN)) {
      pressFlag = false;
    } else {
      pressFlag = true;
      lastPressTime = interruptTime;
      clickCount++;
    }
  }
  lastInterruptTime = interruptTime;
} 

/*---------------------------------------------------------------
 * LVGL display output
 * Transfer rendered RGB565 regions to the LCD through SPI DMA.
 *--------------------------------------------------------------*/
/**
 * @brief Flush an LVGL render region to the ST77961 display.
 *
 * Ends any outstanding LovyanGFX write transaction, submits the requested
 * pixel rectangle through DMA, and releases LVGL to continue rendering.
 *
 * @param disp LVGL display that requested the transfer.
 * @param area Inclusive screen coordinates of the region to update.
 * @param px_map RGB565 pixel data generated by LVGL.
 * @return Nothing.
 * @note Called by LVGL whenever a rendered area must reach the panel.
 */
void my_disp_flush(lv_display_t *disp, const lv_area_t *area, uint8_t *px_map) {
  // DMA owns the transfer that follows, so close the earlier transaction.
  if (gfx.getStartCount() > 0) {
    gfx.endWrite();
  }
  gfx.pushImageDMA(area->x1, area->y1, area->x2 - area->x1 + 1, area->y2 - area->y1 + 1, (lgfx::rgb565_t *)px_map);
  // LVGL may reuse this buffer as soon as flush_ready is called.  Wait for
  // the asynchronous SPI DMA transfer first, as in the verified 1.28-inch
  // implementation, so the next render cannot overwrite pixels in flight.
  gfx.waitDMA();
  lv_display_flush_ready(disp);
}

/*---------------------------------------------------------------
 * LVGL touch input
 * Translate CST816T samples into LVGL pointer states and coordinates.
 *--------------------------------------------------------------*/
/**
 * @brief Provide the latest touch sample to LVGL.
 *
 * Reports a pressed state and valid coordinates when the CST816T has new
 * data. The (0, 0) sample is treated as a stale read rather than an
 * invalid event so the previously reported position remains available.
 *
 * The release event is identified from touch.finger_num == 0 reported by
 * the chip. A long safety timeout also forces a release if the chip ever
 * fails to signal lift-off (a known issue with some CST816T firmware when
 * only the EnTouch bit is enabled).
 *
 * @param indev LVGL input device requesting data; unused by this driver.
 * @param data Destination for the pointer state and coordinates.
 * @return Nothing.
 * @note Called periodically by LVGL through its input-device handler.
 */
static volatile uint32_t touch_press_started_ms = 0;
static const uint32_t TOUCH_MAX_HOLD_MS = 3000;

/**
 * @brief Manual swipe tracking for the main menu.
 *
 * The 1.28-inch reference design uses a custom swipe loop inside the touch
 * callback instead of LVGL's LV_EVENT_GESTURE.  Driving the switch here
 * gives three behaviour wins on the 360 px knob display:
 *   - 30 px threshold (vs LVGL default 50) — short swipes register
 *   - the horizontal component must dominate (abs(dx) > abs(dy)) — tilts
 *     and near-vertical drags are ignored, like the 1.28-inch build
 *   - one switch per touch — a long continuous drag only advances the
 *     menu by one step until the user releases and swipes again, so the
 *     selection feels deliberate instead of "jumping" through items
 */
static bool     swipe_tracking = false;
static bool     swipe_handled = false;
static int16_t  swipe_start_x = 0;
static int16_t  swipe_start_y = 0;
static int16_t  swipe_last_x  = 0;
static int16_t  swipe_last_y  = 0;
static const int16_t SWIPE_MIN_DX = 30;

void my_touchpad_read(lv_indev_t *indev, lv_indev_data_t *data) {
  (void)indev;

  // The CST816T library supplies coordinates directly to the LVGL driver.
  if(touch.available())
  {
    // finger_num == 0 marks the release edge the chip emits at lift-off.
    // Treat it as a release so LVGL doesn't stay in the pressed state and
    // so the next swipe can register a fresh switch.
    if (touch.finger_num == 0) {
      swipe_tracking = false;
      swipe_handled  = false;
      touch_press_started_ms = 0;
      data->state = LV_INDEV_STATE_RELEASED;
      return;
    }

    // Ignore the (0, 0) "invalid" sample but keep the previous position so
    // LVGL continues to see a valid pointer location for the active press.
    int16_t tx = touch.x;
    int16_t ty = touch.y;
    if (tx != 0 || ty != 0) {
      if (!swipe_tracking) {
        swipe_tracking = true;
        swipe_handled  = false;
        swipe_start_x  = tx;
        swipe_start_y  = ty;
      }
      swipe_last_x = tx;
      swipe_last_y = ty;

      // Swipe detection runs only on the main menu so it cannot steal
      // presses from arc and button widgets on the detail screens.
      if (!swipe_handled && lv_screen_active() == ui_Screen1) {
        int dx = (int)swipe_last_x - (int)swipe_start_x;
        int dy = (int)swipe_last_y - (int)swipe_start_y;
        if (abs(dx) >= SWIPE_MIN_DX && abs(dx) > abs(dy)) {
          swipe_handled = true;
          if (dx < 0) {
            if (screen1_index < 2) {
              screen1_index++;
              updataScreen(screen1_index);
            }
          } else if (dx > 0) {
            if (screen1_index > 0) {
              screen1_index--;
              updataScreen(screen1_index);
            }
          }
        }
      }

      data->point.x = tx;
      data->point.y = ty;
    }
    touch_press_started_ms = millis();
    data->state = LV_INDEV_STATE_PRESSED;

#ifdef DEBUG_PRINT
    Serial.print( "Data x " );
    Serial.println( data->point.x );
    Serial.print( "Data y " );
    Serial.println( data->point.y );
#endif
  }
  else
  {
    // If the press timed out without a finger_num==0 release, treat it as
    // released for both LVGL state and swipe tracking so the next press
    // starts clean.  During a normal continuous swipe the chip keeps
    // emitting IRQs so swipe_tracking is preserved across these cycles.
    if (touch_press_started_ms != 0 &&
        (millis() - touch_press_started_ms) > TOUCH_MAX_HOLD_MS) {
      touch_press_started_ms = 0;
      swipe_tracking = false;
      swipe_handled  = false;
    }
    if (touch_press_started_ms == 0) {
      data->state = LV_INDEV_STATE_RELEASED;
    }
    // Otherwise leave data->state unchanged: LVGL preserves the last
    // reported state so a continuous touch keeps tracking correctly.
  }
}

/*---------------------------------------------------------------
 * LCD backlight control
 * Start an 8-bit PWM channel at a visible mid-level brightness.
 *--------------------------------------------------------------*/
/**
 * @brief Initialize the LCD backlight PWM output.
 *
 * Attaches SCREEN_BACKLIGHT_PIN to the shared 5 kHz PWM configuration and
 * starts the display at 50 percent brightness.
 *
 * @note Parameters: None.
 * @return Nothing.
 * @note Called once near the end of setup(), after the UI is initialized.
 */
void initBacklight() {
  ledcAttach(SCREEN_BACKLIGHT_PIN, pwmFreq, pwmResolution);
  ledcWrite(SCREEN_BACKLIGHT_PIN, (50 * 255) / 100);
}

/**
 * @brief Disable touch on SquareLine's transparent overlay buttons.
 *
 * The Studio export places six or seven bg_opa=0 button widgets on top of
 * each detail-page arc.  They have no event callbacks, so any press that
 * lands on them is silently swallowed before the arc below can see it.
 * Clearing CLICKABLE makes the press pass straight through to the arc.
 *
 * @param parent Screen object whose subtree should be cleaned up.
 * @return Nothing.
 * @note Called immediately after _ui_screen_change() finishes creating a
 *       detail screen.
 */
static void disableTransparentButtonClicks(lv_obj_t *parent) {
  if (parent == NULL) return;
  uint32_t cnt = lv_obj_get_child_count(parent);
  for (uint32_t i = 0; i < cnt; i++) {
    lv_obj_t *child = lv_obj_get_child(parent, i);
    if (child == NULL) continue;

    if (lv_obj_check_type(child, &lv_button_class) &&
        lv_obj_get_style_bg_opa(child, LV_PART_MAIN) == 0) {
      lv_obj_remove_flag(child, LV_OBJ_FLAG_CLICKABLE);
    }

    disableTransparentButtonClicks(child);
  }
}

/*---------------------------------------------------------------
 * Encoder button actions
 * Enter the selected detail page or return to the main menu.
 *--------------------------------------------------------------*/
/**
 * @brief Open the detail page selected on the main menu.
 *
 * Maps menu indexes 0, 1, and 2 to the Volume, Bulb, and Light screens.
 * The action is ignored when another screen is already active.
 *
 * @note Parameters: None.
 * @return Nothing.
 * @note Called by encTask() after a single click is confirmed.
 */
void performClickAction()
{
  current_screen = lv_screen_active();
  if(current_screen == ui_Screen1)
  {
    if(current_screen == ui_Screen1)
    {
      if(screen1_index == 0)
      {
        _ui_screen_change(&ui_Screen2, LV_SCR_LOAD_ANIM_FADE_ON, 200 ,0, &ui_Screen2_screen_init);
        // Strip the no-op transparent buttons so presses reach the arc.
        disableTransparentButtonClicks(ui_Screen2);
      }
      else if(screen1_index == 1)
      {
        _ui_screen_change(&ui_Screen3, LV_SCR_LOAD_ANIM_FADE_ON, 200 ,0, &ui_Screen3_screen_init);
        disableTransparentButtonClicks(ui_Screen3);
      }
      else if(screen1_index == 2)
      {
        _ui_screen_change(&ui_Screen4, LV_SCR_LOAD_ANIM_FADE_ON, 200 ,0, &ui_Screen4_screen_init);
        disableTransparentButtonClicks(ui_Screen4);
      }
    }
  }
}

/**
 * @brief Return from a detail page to the main menu.
 *
 * Accepts a double click only on the Volume, Bulb, or Light screen and
 * applies the same short fade transition used by touch navigation.
 *
 * @note Parameters: None.
 * @return Nothing.
 * @note Called by encTask() as soon as two clicks are detected.
 */
void performDoubleClickAction()
{
  current_screen = lv_screen_active();
  if(current_screen == ui_Screen2 || current_screen == ui_Screen3 || current_screen == ui_Screen4)
  {

    _ui_screen_change(&ui_Screen1, LV_SCR_LOAD_ANIM_FADE_ON, 200 ,0, &ui_Screen1_screen_init);
      
  }
}

/*---------------------------------------------------------------
 * Arc value-change callbacks
 * Keep percentage labels and physical PWM outputs synchronized with UI.
 *--------------------------------------------------------------*/
/**
 * @brief Update the displayed Volume percentage.
 *
 * Reads the changed arc value and formats a fixed-width percentage label.
 * This screen is a UI demonstration and does not control audio hardware.
 *
 * @param e LVGL value-change event generated by the Volume arc.
 * @return Nothing.
 * @note Called by LVGL when ui_VolumeArc reports LV_EVENT_VALUE_CHANGED.
 */
static void volume_arc_event_cb(lv_event_t *e)
{
    lv_obj_t *arc = lv_event_get_target_obj(e);
    int value = lv_arc_get_value(arc);
    
    // Preserve label alignment by adding a leading space below 100 percent.
    char volText[8];
    if (value == 100) {
        snprintf(volText, sizeof(volText), "%d%%", value);
    } else {
        snprintf(volText, sizeof(volText), " %d%%", value);
    }
    lv_label_set_text(ui_VolNum, volText);
}

/**
 * @brief Update the temperature value and its PWM duty cycle.
 *
 * Converts the arc's 0-to-200 value into the 0-to-255 range required by
 * the 8-bit PWM output on BULB_LED_PIN.
 *
 * @param e LVGL value-change event generated by the Bulb arc.
 * @return Nothing.
 * @note Called by LVGL when ui_BulbArc reports LV_EVENT_VALUE_CHANGED.
 */
static void bulb_arc_event_cb(lv_event_t *e)
{
    lv_obj_t *arc = lv_event_get_target_obj(e);
    int value = lv_arc_get_value(arc);
    
    // Preserve label alignment by adding a leading space below three digits.
    char bulbText[8];
    if (value >= 100) {
        snprintf(bulbText, sizeof(bulbText), "%d°C", value);
    } else {
        snprintf(bulbText, sizeof(bulbText), " %d°C", value);
    }
    lv_label_set_text(ui_BulbNum, bulbText);
    
    // Scale the 0-to-200 temperature range to the configured 8-bit PWM range.
    int pwm_value = (value * 255) / 200;
    ledcWrite(BULB_LED_PIN, pwm_value);
}

/**
 * @brief Update the Light percentage and LCD backlight level.
 *
 * Converts the arc's 0-to-100 value into the 0-to-255 range required by
 * the 8-bit PWM output on SCREEN_BACKLIGHT_PIN.
 *
 * @param e LVGL value-change event generated by the Light arc.
 * @return Nothing.
 * @note Called by LVGL when ui_LightArc reports LV_EVENT_VALUE_CHANGED.
 */
static void light_arc_event_cb(lv_event_t *e)
{
    lv_obj_t *arc = lv_event_get_target_obj(e);
    int value = lv_arc_get_value(arc);
    
    // Preserve label alignment by adding a leading space below 100 percent.
    char lightText[8];
    if (value == 100) {
        snprintf(lightText, sizeof(lightText), "%d%%", value);
    } else {
        snprintf(lightText, sizeof(lightText), " %d%%", value);
    }
    lv_label_set_text(ui_LightNum, lightText);
    
    // A value of zero leaves the UI running but turns the backlight off.
    int pwm_value = (value * 255) / 100;
    ledcWrite(SCREEN_BACKLIGHT_PIN, pwm_value);
}
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
void loop() {
  EncoderAction action;
  while (encoderActionQueue && xQueueReceive(encoderActionQueue, &action, 0) == pdTRUE) {
    handleEncoderAction(action);
  }

  // LVGL must be serviced continuously for animation and touch response.
  lv_timer_handler();

  vTaskDelay(pdMS_TO_TICKS(5));
}

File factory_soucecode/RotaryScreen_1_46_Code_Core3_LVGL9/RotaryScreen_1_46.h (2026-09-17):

#ifndef _ROTARYSCREEN_1_46_H
#define _ROTARYSCREEN_1_46_H

/*---------------------------------------------------------------
 * Project dependencies
 * Provide the display, touch, UI, LED, and ESP32 platform APIs.
 *--------------------------------------------------------------*/
#include <LovyanGFX.h>
#include <Arduino.h>
#include <esp_heap_caps.h>
#include <cst816t.h>
#include <Wire.h>
#include <lvgl.h>
#include <WiFi.h>
#include <Adafruit_NeoPixel.h>

// Use the UI generated for this sketch explicitly.  A library named `UI`
// installed in the user's global Arduino libraries directory can otherwise
// win the include search and expose a different set of widget symbols.
#include "ui.h"

/*---------------------------------------------------------------
 * Auxiliary I2C bus pins
 * Define the second I2C connection reserved by the board design.
 *--------------------------------------------------------------*/
// GPIO used for data on the auxiliary I2C bus.
#define I2C_SDA_PIN     38
// GPIO used for the clock on the auxiliary I2C bus.
#define I2C_SCL_PIN     39

/*---------------------------------------------------------------
 * Power indicator and addressable LED ring
 * Keep these values aligned with the board schematic.
 *--------------------------------------------------------------*/
// Active-low power indicator output.
#define POWER_LIGHT_PIN 40                                           
// Data output shared by the eight addressable LEDs.
#define LED_PIN         48
// Number of NeoPixel devices connected in the ring.
#define LED_NUM         8  

/*---------------------------------------------------------------
 * Rotary encoder input pins
 * Read the quadrature phases and the integrated push button.
 *--------------------------------------------------------------*/
// Encoder phase A input.
#define ENCODER_A_PIN   45
// Encoder phase B input.
#define ENCODER_B_PIN   42
// Active-low encoder push-button input.
#define SWITCH_PIN      41

/*---------------------------------------------------------------
 * LED definitions retained by the original project
 * These repeated definitions intentionally preserve source logic.
 *--------------------------------------------------------------*/
#define POWER_LIGHT_PIN   40                                           
#define LED_PIN           48
#define LED_NUM           8  

/*---------------------------------------------------------------
 * PWM-controlled outputs
 * Drive the LCD backlight and the board's bulb demonstration LED.
 *--------------------------------------------------------------*/
// LCD backlight PWM output.
#define SCREEN_BACKLIGHT_PIN 46

// Bulb demonstration PWM output.
#define BULB_LED_PIN 43

// Logical display dimensions used by both LovyanGFX and LVGL.
const uint32_t screenWidth  = 360;
const uint32_t screenHeight = 360;

// Shared PWM timing: 5 kHz with an 8-bit duty cycle from 0 to 255.
const int pwmFreq = 5000;
const int pwmResolution = 8;

/*---------------------------------------------------------------
 * Encoder and push-button state
 * Share short-lived input state between the interrupt and RTOS task.
 *--------------------------------------------------------------*/
// Encoded direction awaiting processing: 1, 0, or -1 when idle.
volatile int8_t position_tmp = -1;  
// Reserved phase-A samples retained for compatibility with the sketch.
volatile int8_t currentA = 0;
volatile int8_t lastA = 0;

// Time of the most recent accepted button press.
volatile unsigned long lastPressTime = 0;   
// Records whether the button is currently considered pressed.
volatile bool pressFlag = false;      
// Number of accepted presses inside the double-click window.
volatile int clickCount = 0;  

// Button debounce interval, adjusted after single and double clicks.
unsigned long debounceTime = 30;   
// Maximum interval used to classify two presses as a double click.
const unsigned long doubleClickTime = 300; 

// Encoder counters used for direction logging and sanity checking.
int last_counter = 0;
int counter = 0;
// Current and previous logic levels sampled from encoder phase A.
int currentStateCLK;
int lastStateCLK;

// Human-readable direction included in serial diagnostic output.
String currentDir = "";
// Suppresses the first transition in one encoder direction at startup.
bool one_test = false;

/*---------------------------------------------------------------
 * NeoPixel animation state
 * Maintain the LED ring object and progress through each test pattern.
 *--------------------------------------------------------------*/
Adafruit_NeoPixel led = Adafruit_NeoPixel(LED_NUM, LED_PIN, NEO_GRB + NEO_KHZ800);  
// Allows the LED task to run or request a clean stop.
bool isLed = true;
// Counts completed repetitions within the current animation pattern.
uint8_t ledCount = 0;
// Stores the current global brightness during the breathing pattern.
int8_t ledBrightness = 0;

// Reserved touch coordinates retained by the original project.
uint16_t touchX, touchY;
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
